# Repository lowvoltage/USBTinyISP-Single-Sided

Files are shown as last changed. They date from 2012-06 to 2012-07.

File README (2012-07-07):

Single-sided PCB version of the USBTinyISP v.2.0 AVR programmer

Original USBTinyISP v.2.0 design: LadyAda @ http://www.ladyada.net/make/usbtinyisp/
Original Single-sided PCB design: Jim Qode @ http://www.symbolengine.com/index.php/usbtinyisp-single-side-board-version/

Author: Dimitar Kovachev, http://lowvoltage.wordpress.com/

Released under the Creative Commons Attribution Share-Alike 3.0 license
http://creativecommons.org/licenses/by-sa/3.0/

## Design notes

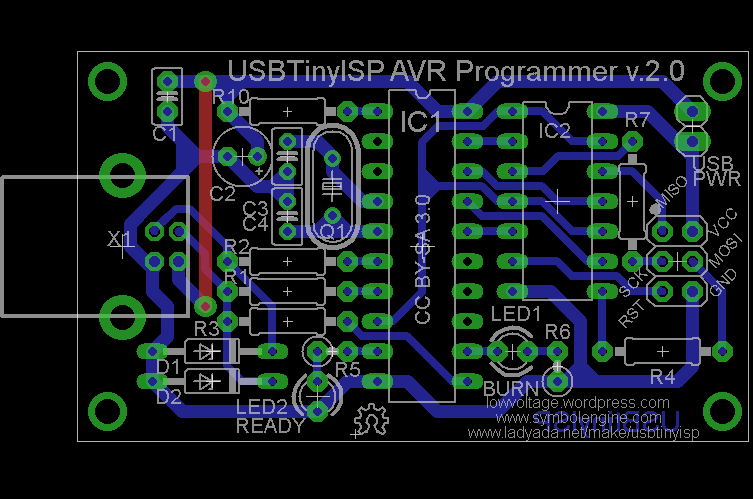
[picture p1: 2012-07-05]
PCB_v0.08.png

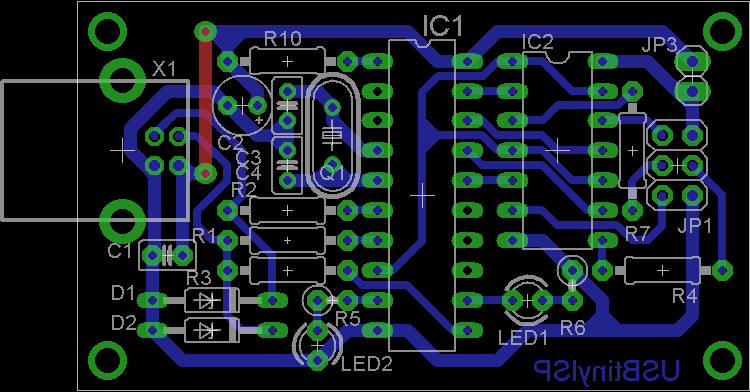
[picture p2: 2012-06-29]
PCB_v0.05.png

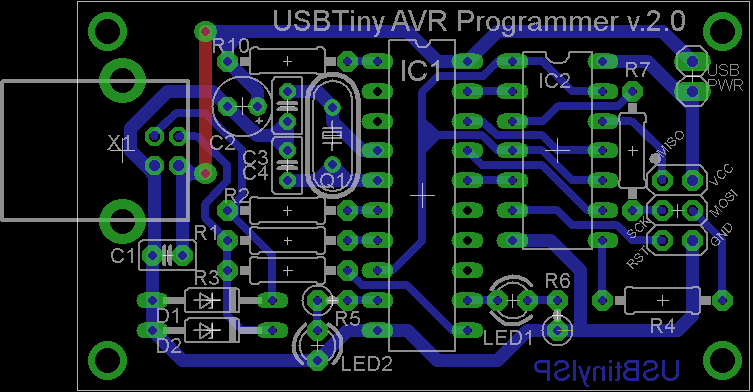
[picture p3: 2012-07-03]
PCB_v0.06.png

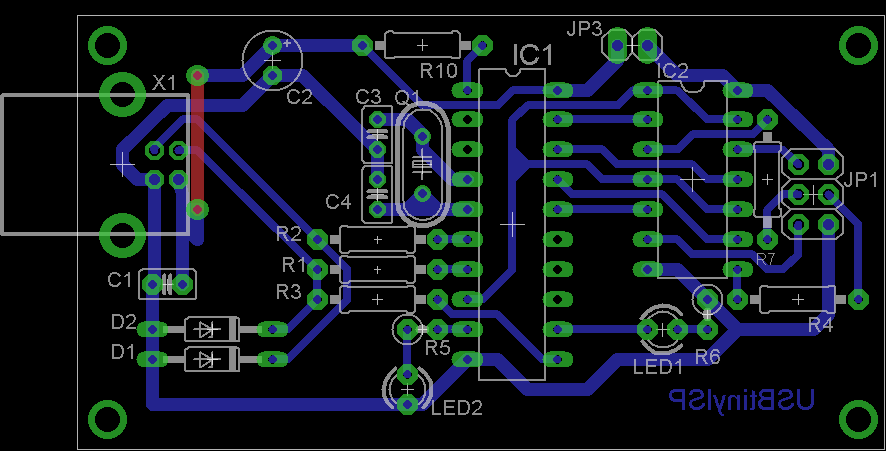
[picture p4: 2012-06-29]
PCB_v0.03.png

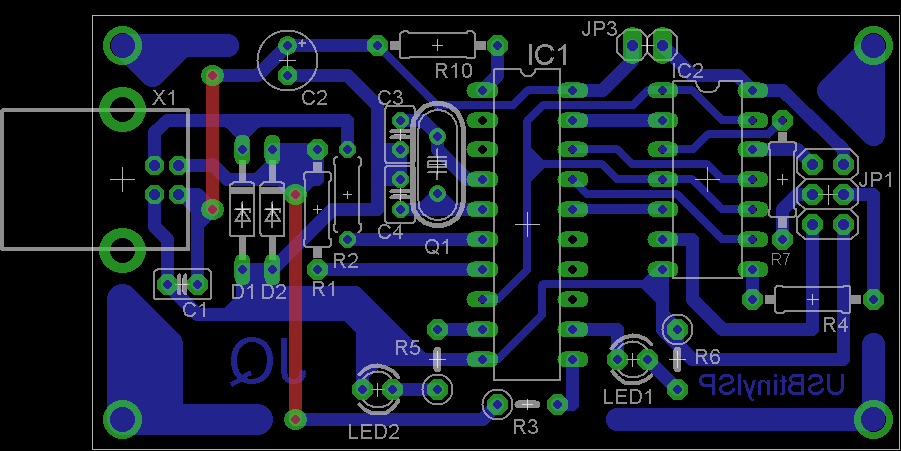
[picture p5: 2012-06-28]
PCB_v0.02.png

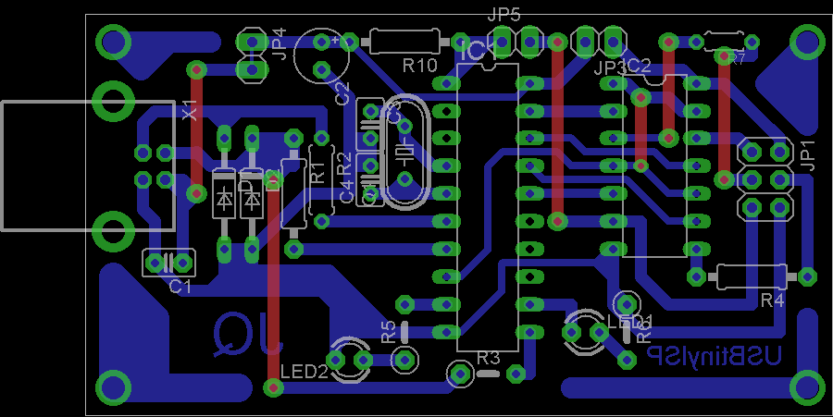
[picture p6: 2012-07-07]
PCB_v0.00.png

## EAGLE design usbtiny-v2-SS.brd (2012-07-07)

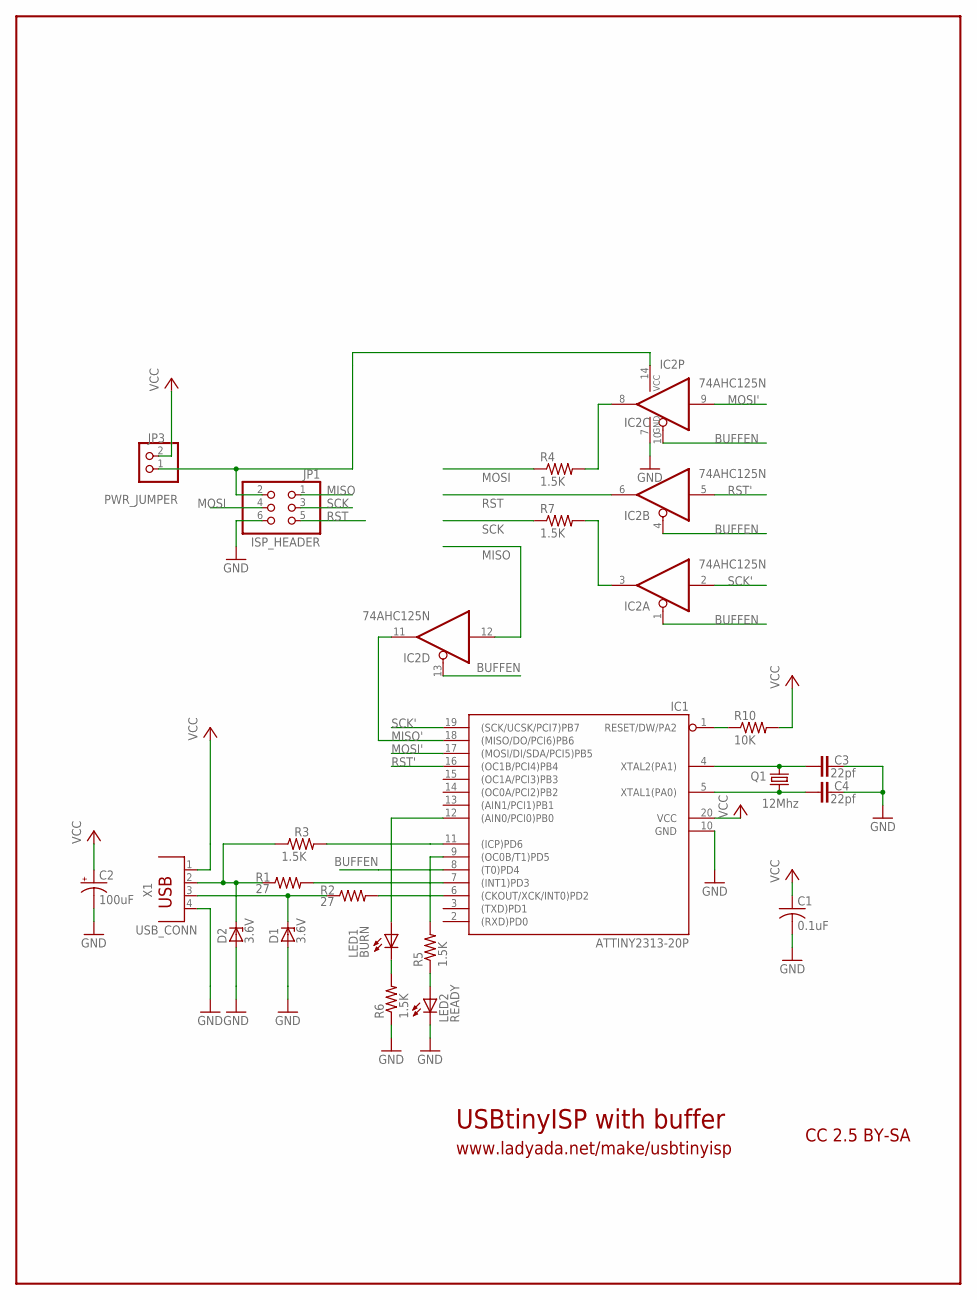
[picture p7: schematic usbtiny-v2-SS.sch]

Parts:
C1: 0.1uF; C025-025X050
C2: 100uF; E2,5-5
C3, C4: 22pf; C025-025X050
D1, D2: 3.6V; DO35Z10
IC1: ATTINY2313-20P; DIL20
IC2: 74AHC125N; DIL14
JP1: ISP_HEADER; 2X03
JP3: PWR_JUMPER; 1X02
LED1: BURN; LED3MM
LED2: READY; LED3MM
Q1: 12Mhz; HC49/S
R1, R2: 27; 0207/10
R3, R4, R7: 1.5K; 0207/10
R5, R6: 1.5K; 0207/2V
R10: 10K; 0207/10
X1: USB_CONN; PN61729

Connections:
BUFFEN: IC1.8 ((T0)PD4), IC2.1 (OE), IC2.4 (OE), IC2.10 (OE), IC2.13 (OE)
GND: C1.2, C2.-, C3.2, C4.2, D1.A, D2.A, IC1.10 (GND), IC2.7 (GND), JP1.6, LED2.K (C), R6.1, X1.4
MISO: IC2.12 (I), JP1.1
MISO': IC1.18 ((MISO/DO/PCI6)PB6), IC2.11 (O)
MOSI: JP1.4, R4.1
MOSI': IC1.17 ((MOSI/DI/SDA/PCI5)PB5), IC2.9 (I)
unnamed: D2.C, R1.1, R3.1, X1.2
unnamed: D1.C, R2.1, X1.3
unnamed: IC1.7 ((INT1)PD3), R1.2
unnamed: IC1.6 ((CKOUT/XCK/INT0)PD2), R2.2
unnamed: IC1.12 ((AIN0/PCI0)PB0), LED1.A
unnamed: LED1.K (C), R6.2
unnamed: IC1.1 (RESET/DW/PA2), R10.1
unnamed: IC1.9 ((OC0B/T1)PD5), R5.2
unnamed: LED2.A, R5.1
unnamed: IC2.3 (O), R7.2
unnamed: IC2.8 (O), R4.2
unnamed: IC1.11 ((ICP)PD6), R3.2
unnamed: C3.1, IC1.4 (XTAL2(PA1)), Q1.2
unnamed: C4.1, IC1.5 (XTAL1(PA0)), Q1.1
RST: IC2.6 (O), JP1.5
RST': IC1.16 ((OC1B/PCI4)PB4), IC2.5 (I)
SCK: JP1.3, R7.1
SCK': IC1.19 ((SCK/UCSK/PCI7)PB7), IC2.2 (I)
VCC: C1.1, C2.+, IC1.20 (VCC), JP3.2, R10.2, X1.1
VCC_REMOTE: IC2.14 (VCC), JP1.2, JP3.1

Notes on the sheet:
USBtinyISP with buffer
www.ladyada.net/make/usbtinyisp
CC 2.5 BY-SA

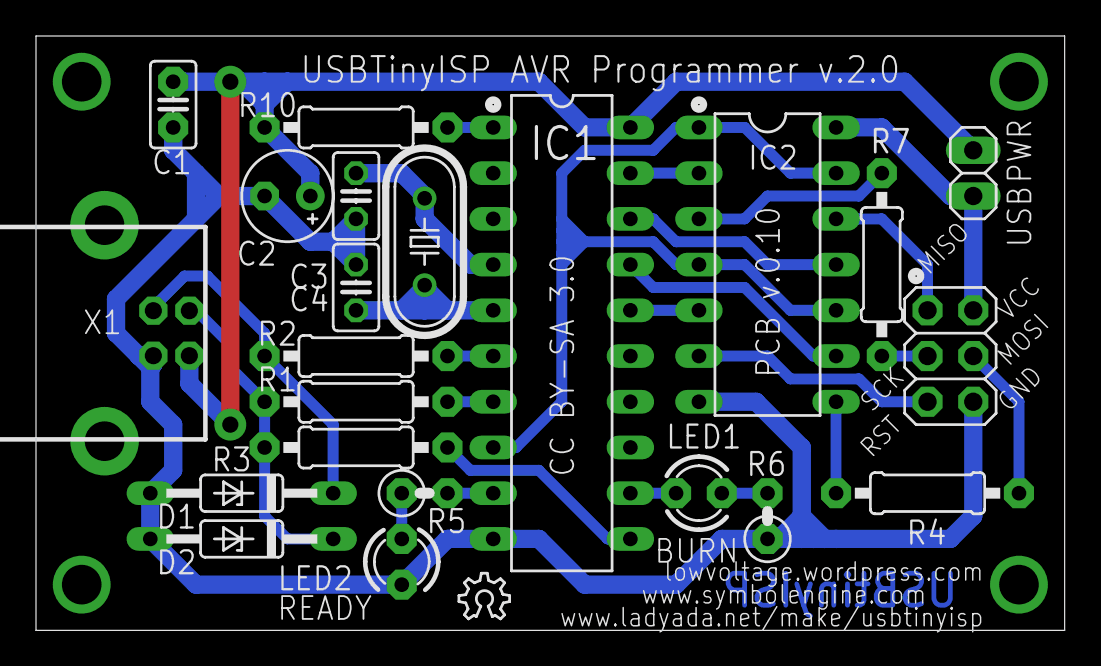
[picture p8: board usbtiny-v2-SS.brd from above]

Board: 2 copper layers, 57.1 x 33.0 mm, 23 parts (0 on the bottom side), 26 nets.

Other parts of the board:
U$1: OSHW_6X100_NOTEXT

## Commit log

2012-06-28 Original version
    [usbtinyisp v2.0 SS.brd, usbtinyisp v2.0 SS.sch]
2012-06-28 Version 0.01
    [usbtinyisp v2.0 SS.brd, usbtinyisp v2.0 SS.sch]
2012-06-28 Removed spaces from filenames
    [usbtiny-v2-SS.brd, usbtiny-v2-SS.sch]
2012-06-28 Version 0.02
    [usbtiny-v2-SS.brd, usbtiny-v2-SS.sch]
2012-06-28 Version 0.03
    [usbtiny-v2-SS.brd, usbtiny-v2-SS.sch]
2012-06-29 Version 0.04
    [usbtiny-v2-SS.brd]
2012-06-29 Version 0.05
    [usbtiny-v2-SS.brd]
2012-07-03 Version 0.06
    [usbtiny-v2-SS.brd]
2012-07-03 Version 0.07
    [usbtiny-v2-SS.brd]
2012-07-04 Schematic fixes, partial
    [usbtiny-v2-SS.sch]
2012-07-05 Version 0.08 - Final tweaks
    [usbtiny-v2-SS.brd, usbtiny-v2-SS.sch]
2012-07-05 Added pin-1 dots
    [usbtiny-v2-SS.brd]
2012-07-05 Version 0.09 - Vector fonts
    [usbtiny-v2-SS.brd]
2012-07-06 Add PCB version. Optimize wires. Fix jumper clearance
    [usbtiny-v2-SS.brd]
2012-07-07 Fixed board dimensions
    [usbtiny-v2-SS.brd]
2012-07-07 Updated initial PCB image

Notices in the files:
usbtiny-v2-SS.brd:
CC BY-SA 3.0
